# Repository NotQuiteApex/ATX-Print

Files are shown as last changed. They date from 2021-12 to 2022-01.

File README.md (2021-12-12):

# Full ATX PC Case
My custom designed and 3D printed PC case, housing a full ATX motherboard, ATX PSU, 120mm fans, and a Coolermaster 240mm AIO. Features full PCIe slots and support for <285mm GPUs. There is also an alternate version for SFX power supplies.

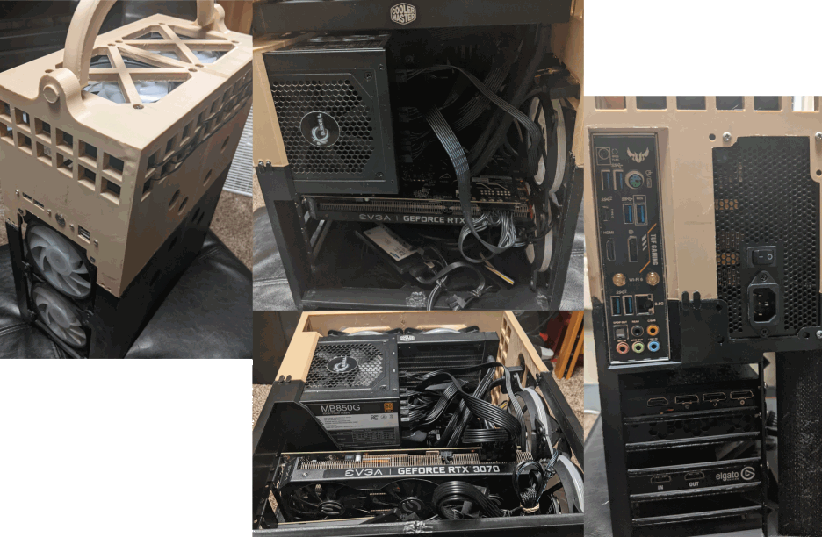
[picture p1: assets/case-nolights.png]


I designed this case from the ground up based on any and all available documentation on the standard specs for ATX parts. The main case body is to be printed in 4 parts because of the size limitations of my Ender 3 Pro 3D printer, which can only print 235x235x300mm^3. The STEP files included are the original parts, designed in Autodesk Inventor 2021. The SCAD files in the repo are meant to be a recreation of the parts in an open format that is easy to edit and export for free (no licensing for Autodesk software) and thus are a Work-in-Progress.

If you would like to print the current version, look at the README inside the STEP folder. It includes instructions on printing and assembly.

# License
Copyright (c) 2021 Logan Hickok-Dickson. This project is licensed under the zlib/libpng license, see LICENSE.md for more details.

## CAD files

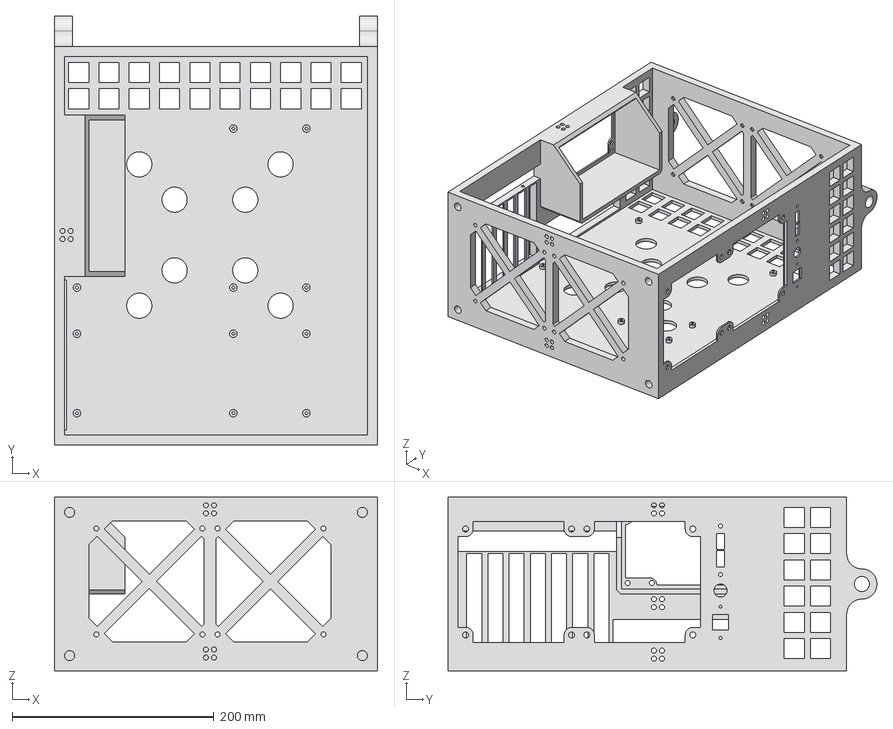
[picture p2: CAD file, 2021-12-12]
STEP/__full-case-atx.step
320.0 x 425.0 x 172.0 mm

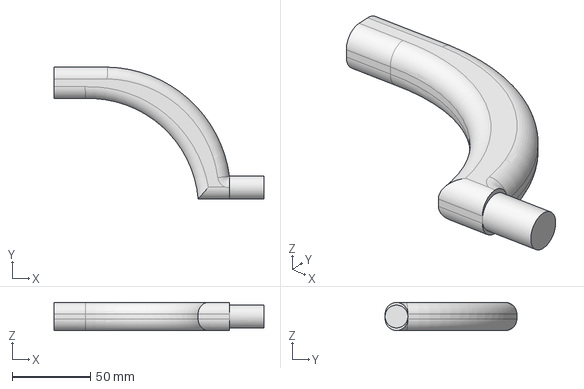
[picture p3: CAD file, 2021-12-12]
STEP/handle-end.step
133.9 x 84.0 x 18.0 mm

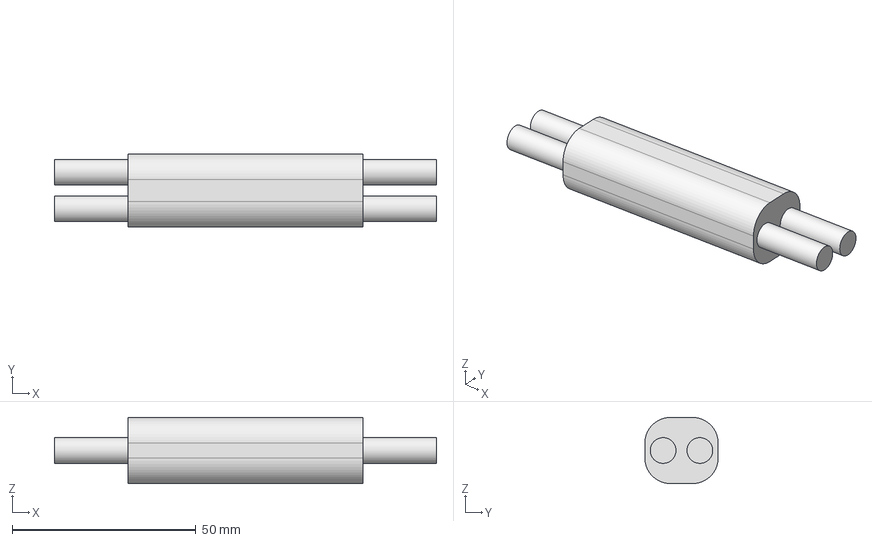
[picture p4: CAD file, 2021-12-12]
STEP/handle-mid.step
104.0 x 20.0 x 18.0 mm

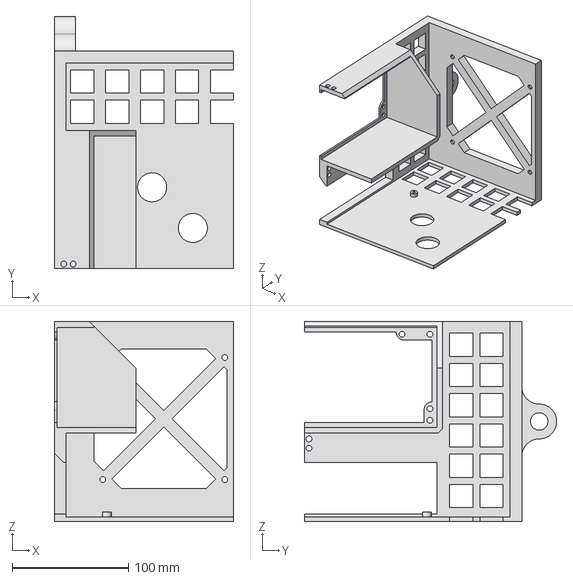
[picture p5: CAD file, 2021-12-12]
STEP/case-top-left-atx.step
154.0 x 217.0 x 172.0 mm

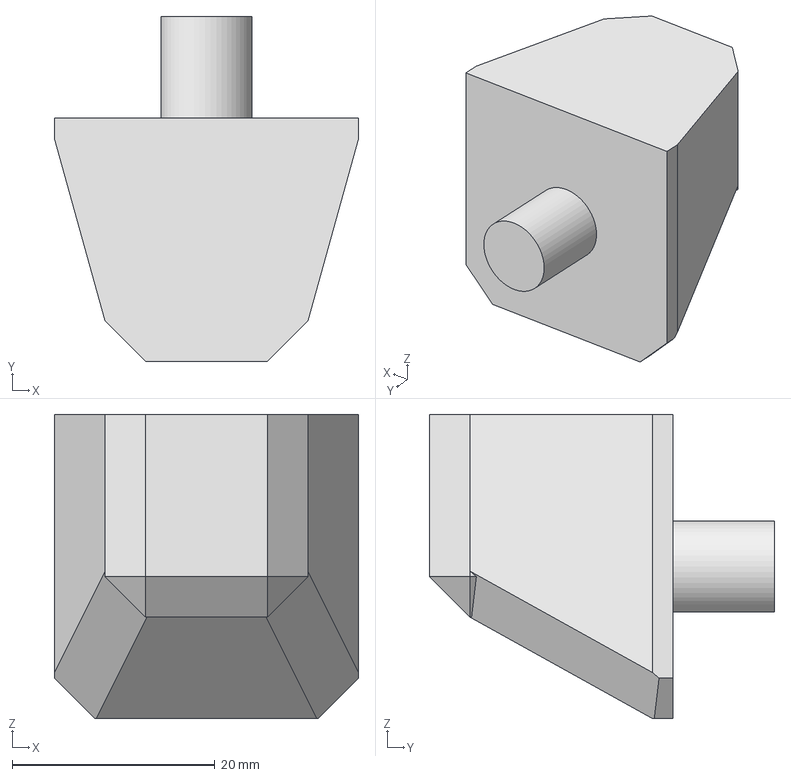
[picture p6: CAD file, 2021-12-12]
STEP/case-foot.step
30.0 x 34.0 x 30.0 mm

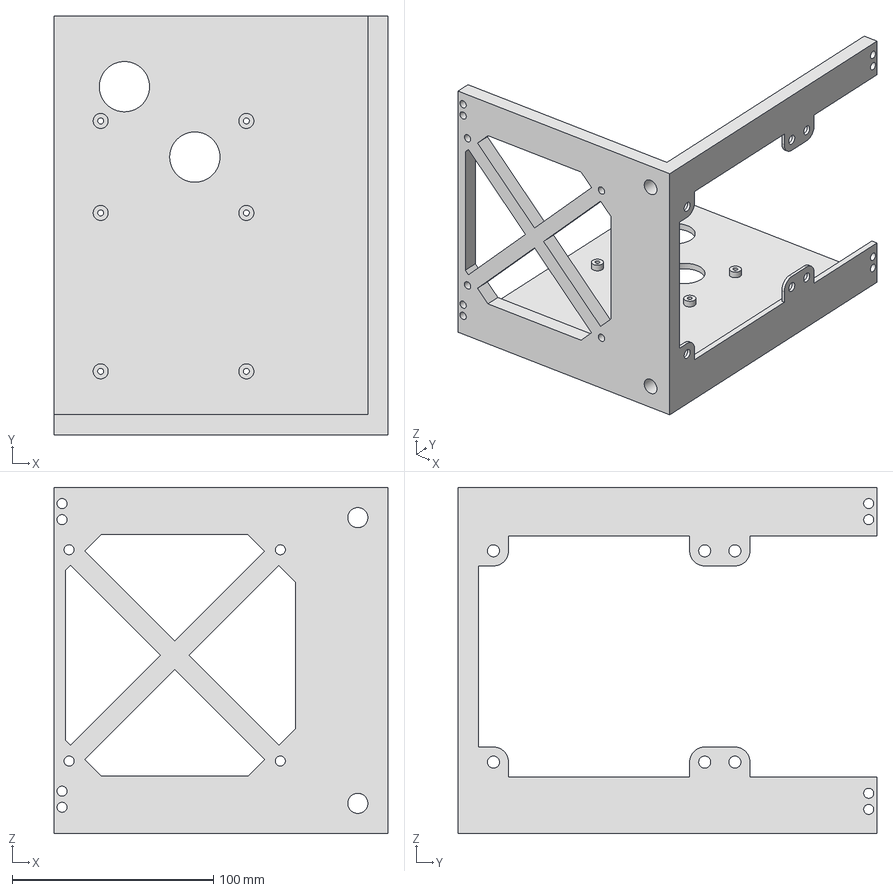
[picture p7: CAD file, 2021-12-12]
STEP/case-bot-right.step
166.0 x 208.0 x 172.0 mm

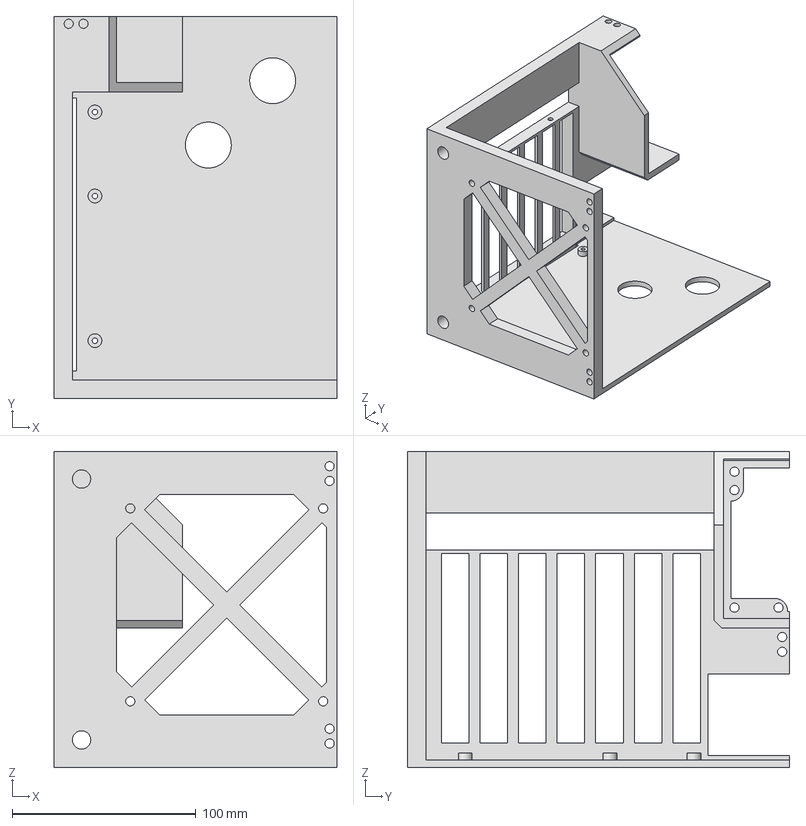
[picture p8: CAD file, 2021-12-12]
STEP/case-bot-left-atx.step
154.0 x 208.0 x 172.0 mm

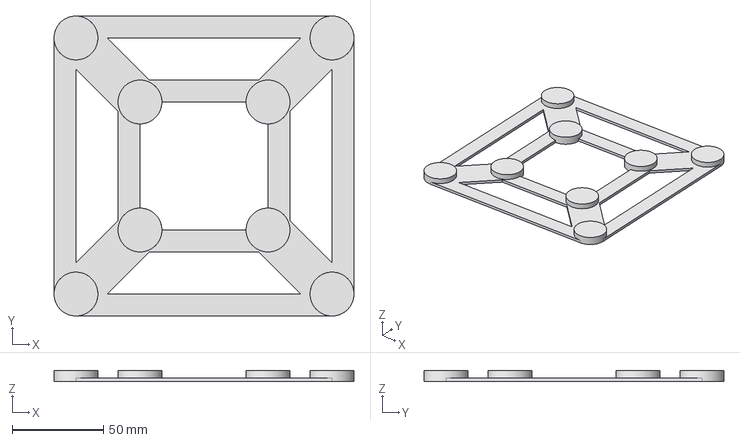
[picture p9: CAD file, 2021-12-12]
STEP/bracket-back.step
164.0 x 164.0 x 6.00 mm

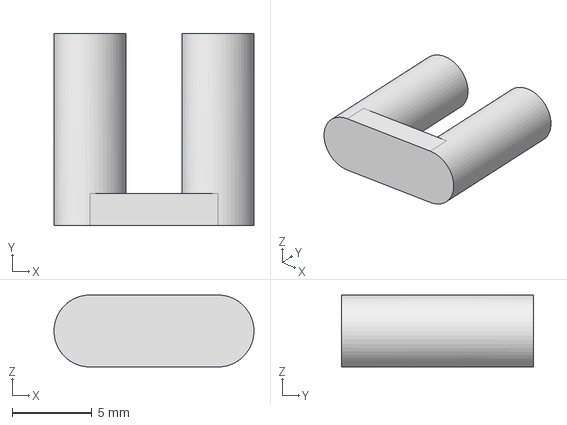
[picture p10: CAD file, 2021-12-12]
STEP/bracket-mini.step
12.5 x 12.0 x 4.50 mm

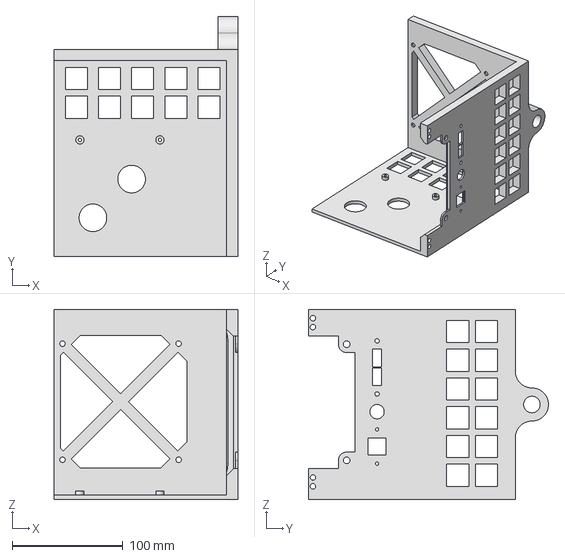
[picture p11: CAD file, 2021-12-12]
STEP/case-top-right.step
166.0 x 217.0 x 172.0 mm

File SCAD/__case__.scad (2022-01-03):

// Full assembly of the case.

use <body.scad>;
use <body-foot.scad>;
use <bracket-back.scad>;
use <bracket-mini.scad>;
use <handle-end.scad>;
use <handle-mid.scad>;

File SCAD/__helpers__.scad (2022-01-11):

module prism(l, w, h){
    polyhedron(
        points=[[0,0,0], [l,0,0], [l,w,0], [0,w,0], [0,w,h], [l,w,h]],
        faces=[[0,1,2,3],[5,4,3,2],[0,4,5,1],[0,3,4],[5,2,1]]
    );
}

prism(10, 5, 3);

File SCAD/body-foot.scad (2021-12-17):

module case_foot() {
    cylinder(10, 9/2, 9/2);
    //cube([30,30,40]);
    CubePoints = [
      [  5,  5,  0 ],  //0
      [ 30,  5,  0 ],  //1
      [ 30, 25,  0 ],  //2
      [  5, 25,  0 ],  //3
      [  0,  0, 40 ],  //4
      [ 30,  0, 40 ],  //5
      [ 30, 30, 40 ],  //6
      [  0, 30, 40 ]   //7
    ];
      
    CubeFaces = [
      [0,1,2,3],  // bottom
      [4,5,1,0],  // front
      [7,6,5,4],  // top
      [5,6,2,1],  // right
      [6,7,3,2],  // back
      [7,4,0,3]   // left
    ];
      
   translate([-15,-15,-40]) polyhedron( CubePoints, CubeFaces );
}

case_foot();

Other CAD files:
STEP/__full-case-sfx.step
STEP/case-top-left-sfx.step
STEP/case-bot-left-sfx.step
SCAD/body.scad
SCAD/bracket-mini.scad

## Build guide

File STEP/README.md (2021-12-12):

# STEP files
Included here are all the files to create and print the case. These files are intended to be printed with an Ender 3, or some equivalent printer with a similar build volume. There are two versions of some files depending on whether you are using an SFX or ATX power supply unit, they are labeled as such.

In case you'd prefer to edit and/or modify what portions of the big case are printed, the full case is included as full-case.step.

# How to print
Simply open the STEP files in your choice of slicer and create the save the GCODE for the print. If you cannot open STEP files, you should convert the files to STL. You can do this easily with TinkerCAD, by importing the STEP and exporting it as STL with no modifications.

| Part | Filename | Amount | Notes. |
| - | - | - | - |
| Back Bracket | `bracket-back.step` | 1 | Goes on the back side of the case to connect the big four pieces. |
| Mini Bracket | `bracket-mini.step` | 12 | Helps connect smaller bits of the case together. |
| Handle Middle | `handle-mid.step` | 1 | The center piece connecting the two handle ends together. |
| Handle Ends | `handle-end.step` | 2 | The two ends of the handle that form the bridge of the handle to the case. |
| Case Top Right | `case-top-right.step` | 1 | Top right portion of the case. |
| Case Bottom Right | `case-bot-right.step` | 1 | Bottom right portion of the case. |
| Case Top Left | `case-top-left-<ff>.step` | 1 | Top left portion of the case. Note: `<ff>` refers to the form factor of the power supply you're using, being ATX or SFX. |
| Case Bottom Left | `case-bot-left-<ff>.step` | 1 | Bottom left portion of the case. Note: `<ff>` refers to the form factor of the power supply you're using, being ATX or SFX. |

Take caution in printing, as warping prints can make assembly more difficult and throw off measurements.

# How to assemble
You will need a soldering iron that can meld the plastic you used together, you can cut lengths of plastic from your spool to use or just use the existing plastic as the bond. Be careful of toxins the plastic may produce when heated.

0. Connect the two handle ends to the middle pieces. Meld the pieces together.
0. Place the back bracket down on a steady large surface (like a table).
0. Connect the top two pieces together with the handle. Do not meld the pieces together, otherwise the handle cannot rotate.
0. Place the connected pieces from above as well as the bottom two case pieces and arrange them over the back bracket.
0. Push down on all the pieces to join them with the back bracket by the force of friction, leave the case laid down.
0. Connect all the mini brackets around the case such as between the right two pieces, the bottom pieces, and the left two pieces.
0. The mini brackets that connect to the top of the PSU housing will need to be cut inside the housing to allow the PSU to fit. Do that.
0. Adjust the pieces so that the four main body pieces line up and are flush with each other as best as possible.
0. While the case remains laid down, take the iron and meld the four main pieces together. Additional connection can be made by using the mini brackets as plastic to connect the pieces together.
0. As most of the case is connected while laid down, it can be stood up. Use this opportunity to meld more of the outside of the case that was inaccessible while it was laid down.
0. Place the feet into the slots on the bottom of the case. Line them up square with the case and use the iron to meld them to the case. Careful not to burn yourself while keeping the feet lined up.
0. Also meld the top of the feet on the inside of the case to the floor of the case.
0. That's all! You can now build in the case as you normally would.

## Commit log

2021-12-12 Initial commit.
    [__full-case-atx.step, __full-case-sfx.step, bracket-back.step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]
2021-12-17 do base board of body
    [body.scad]
2021-12-17 add mini bracket
    [bracket-mini.scad]
2021-12-17 add case foot
    [body-foot.scad]
2021-12-25 add sides to the body
    [body.scad]
2022-01-03 add edges of body
    [__case__.scad, body.scad]
2022-01-03 add holes for eATX (not tested) and use variables for stuff
    [body.scad]
2022-01-07 add variable for screw insert diameter
    [body.scad]
2022-01-08 add handle notches
    [body.scad]
2022-01-11 add fan space at the top
    [__helpers__.scad, body.scad]
